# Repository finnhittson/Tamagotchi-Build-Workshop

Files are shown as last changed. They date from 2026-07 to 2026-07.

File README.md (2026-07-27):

# Tamagotchi Build Workshop

This repo documents a Tamagotchi that was created as a lab64 workshop at Stanford University. The idea of the workshop was for students to come into the lab64 makerspace to receive materials and assembly instructions, spend a few hours building, eat a free dinner, and then leave with a fully assembled and functioning Tamagotchi. This project was a collaboration between me, [Sydney Yan](https://www.linkedin.com/in/sydney-yan/), and [Dani Algazi](https://www.linkedin.com/in/dani-algazi-17a7431b2/). I was responsible for creating the PCB, Sydney wrote all the code, and Dani created the enclosure. To see our Tamagotchi in action please visit this [link](https://youtu.be/EQx-8vsQdow).
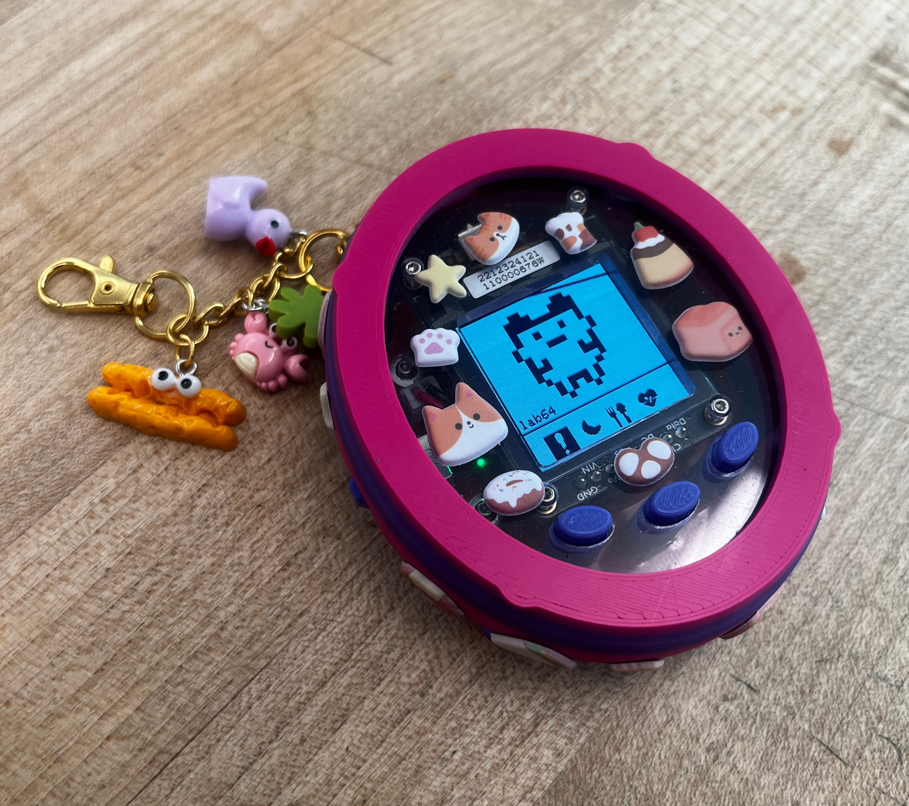
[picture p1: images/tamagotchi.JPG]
tamagotchi


## Electrical

The electronics inside the Tamagotchi were a custom PCB that utilized a [ItsyBitsy](https://www.adafruit.com/product/3675?srsltid=AfmBOooAwEcHuKG2jr8HvIwYrDCV_mU2HbkCFx2qz2rQIsxoqrmatH5F) microcontroller, [128x128 OLED Graphic Display](https://www.adafruit.com/product/5297) by Adafruit, a [2000mAh battery](https://www.adafruit.com/product/2011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), three buttons, and a few other electronics. A full bill of materials is avaliable in the `electrical/` directory. A schematic of the circuit is the following image.

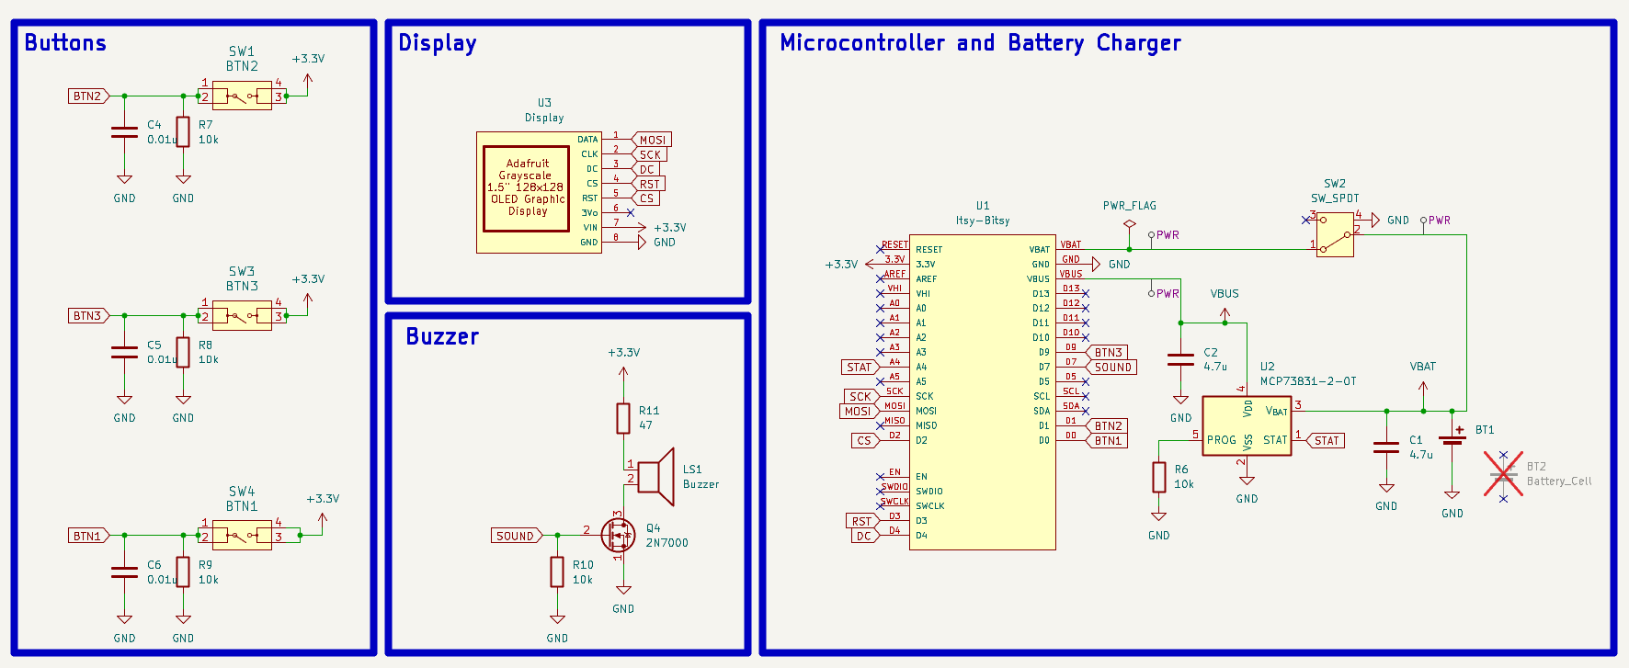
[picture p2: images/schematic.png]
schematic


The buttons are the main control buttons for the Tamagotchi. They are nominally pulled up and go low when pressed. There is also a bypass capacitor to help eliminate switch bounce. The display is controlled by the ItsyBitsy microcontroller through a SPI bus and displays the Tamagotchi and all of its actions. The buzzer is for added sound effects but was never implemented in software due to time constraints. The final block is the ItsyBitsy microcontroller which is connected to a one cell LiPo battery charger circuit. The battery output voltage is fed through a power switch which is then ORed with the VBUS voltage, if present, on the ItsyBitsy breakout board to be regulated to 3.3V and power all other devices. The PCB layout is the following image.

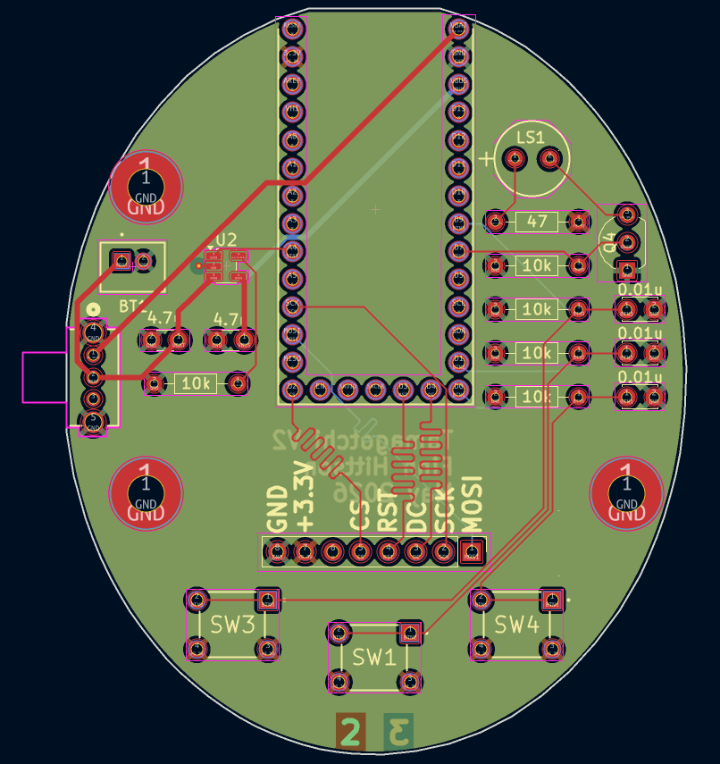
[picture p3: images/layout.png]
layout


The shape is an oval since most real Tamagotchi's are "egg" shaped. The SPI bus lines are length matched not because we expect to use this board at very high frequencies, but rather because it looks cool and I wanted to try it. At the bottom of the PCB are embedded board labels to make sure the stack up was done in the correct order. We opted for three mounting holes due to spacing and because any plane can be constrained by only three points of contact. The following images are renderings of the PCB with and without the display.

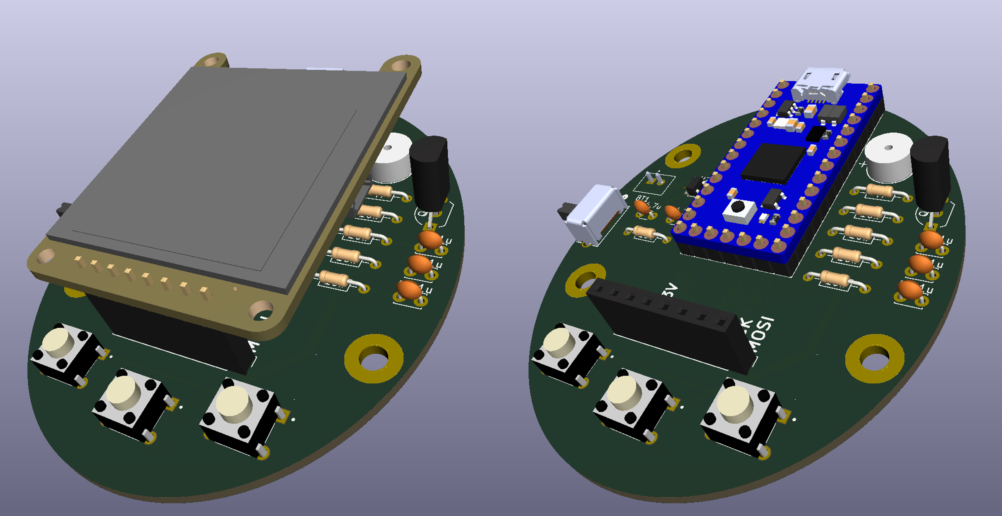
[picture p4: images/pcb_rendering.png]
pcb_rendering


## Software

The software for the Tamagotchi was created and written by [Sydney Yan](https://www.linkedin.com/in/sydney-yan/). Her [repository](https://github.com/sydneyyan/lab64-tamagotchi/tree/main) has installation instructions. The code is structured as an event driven framework. The events were defined as button presses which let the user move their cursor selection between the different actions. The outside most buttons move the cursor either left or right and the middle button is the select button.

cursor

Then the middle button allows the user to select the action, and the Tamagotchi would do the action. The actions are screaming, exercising (running), sleeping, and eating (farting).

actions

The images of the Tamagotchi are then translated as a bitmap to the display. We found many images online of Tamagotchi characters and their actions in bitmap images and translated them manually to an array of ones and zeros to be displayed on the OLED 128x128 display. An example of one of these images we considered was the following. With each button press the display changes the bitmap of the Tamagotchi character or the cursor selection to give the animation effect. 

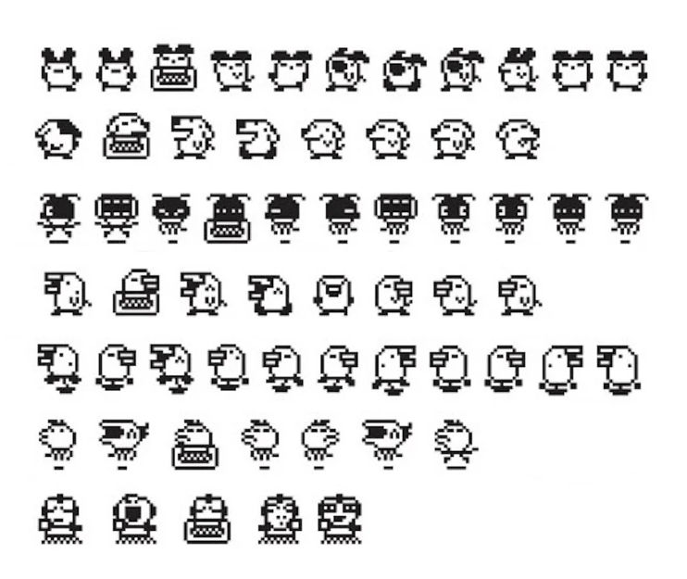
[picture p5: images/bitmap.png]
bitmap


## Mechanical

The enclosure was created and designed by [Dani Algazi](https://www.linkedin.com/in/dani-algazi-17a7431b2/). His Onshpae file for this project is so beautifully organized you have to see [it](https://cad.onshape.com/documents/d4130be6a1970f53ef730a90/w/6fa9feb7c0a58738c3d2d12f/e/90ee6ce4a11ee68d4a759c51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) for yourself. 
The enclosure is made of three main pieces; the top and bottom part of the enclosure, and the front cover. The following exploded view of the assembly shows these parts.

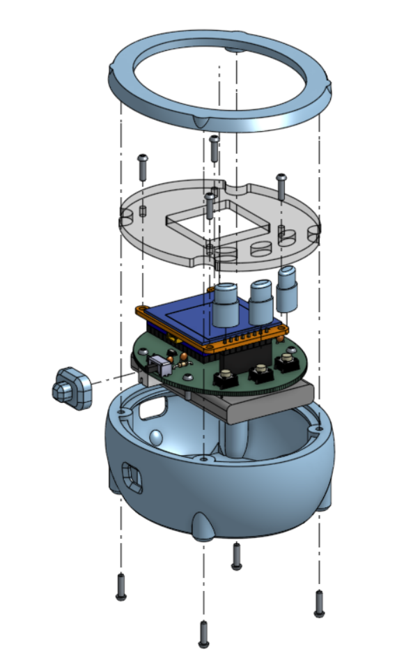
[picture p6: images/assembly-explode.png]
assembly-exploded


The bottom piece holds the battery and the  PCB in place with heat set inserts embedded into the frame. The translucent front cover piece snaps into the top part of the enclosure. This then fits to the bottom part of the enclosure, sealing the electronics inside. The top part of the enclosure has heat set inserts and screws to the bottom part of the enclosure. We also had to add button and switch extenders so that the user could press the buttons and flip the power switch from the outside of the enclosure. Fully assembled the Tamagotchi 3D rendering looks like the following. The files `Assembly Instructions.pdf` describe how to assemble a Tamagotchi with many more photos explaining each step.
comparison

## Special Thanks

Huge thank you to Dani and Sydney for helping me create this. It was a ton of fun to work with you and see our rendition of Tamagotchi come to life. Lets do it again.

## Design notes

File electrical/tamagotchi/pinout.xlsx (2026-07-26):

Net Name | IO | Pin Number | Description | Line states
BTN3 | Input | D5 | Left button | Line HIGH when pressed, LOW when not pressed
BTN2 | Input | D1 | Middle button | Line HIGH when pressed, LOW when not pressed
CS | Output | D3 | Chip select line for display | LOW when selecting the display and HIGH when not selecting
MOSI | Output | MOSI | Data line from ItsyBitsy to display | Data line
SOUND | Output | D7 | PWM line to control buzzer | PWM line
BTN1 | Input | D0 | Right button | Line HIGH when pressed, LOW when not pressed
SCK | Output | SCK | SPI clock line | SPI bus clock line
STAT | Input | A4 | Battery charge status from battery charger IC | LOW is battery charging, HIGH is battery charging complete
RST | Output | D2 | Reset pin for display | Reset line, active LOW
DC | Output | D4 | Data or command selector pin. Tells display controller whether incomming packet is data or a command | HIGH is for data, LOW is for command

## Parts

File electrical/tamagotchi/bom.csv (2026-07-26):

Reference | Qty | Value | Supplier | Supplier PN
BT1 | 50 | Battery_Conn | DigiKey | 455-1704-ND
BT2 | 50 | Battery_Cell | DigiKey | 1528-1857-ND
C1,C2 | 100 | 4.7u | DigiKey | 399-14393-2-ND
C4,C5,C6 | 150 | 0.01u | DigiKey | BC1084TR-ND
LS1 | 50 | Speaker | DigiKey | 433-1192-ND
R6,R7,R8,R9,R10 | 250 | 10k | DigiKey | CF14JT10K0TR-ND
SW1 | 150 | BTN2 | DigiKey | EG1829-ND
SW2 | 50 | SW_SPDT | DigiKey | CKN9559-ND
U1 | 50 | Itsy-Bitsy | DigiKey | 1528-2619-ND
U2 | 50 | MCP73831-2-OT | DigiKey | MCP73831T-2ACI/OTTR-ND
U3 | 50 | Display | Adafruit | 4741

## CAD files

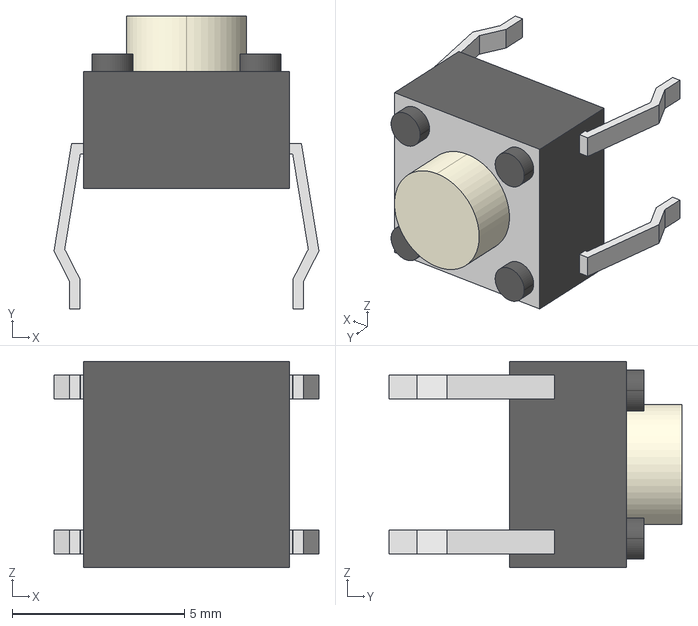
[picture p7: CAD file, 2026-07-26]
electrical/tamagotchi/3d_models/b3f-1020.stp
7.70 x 8.50 x 6.00 mm

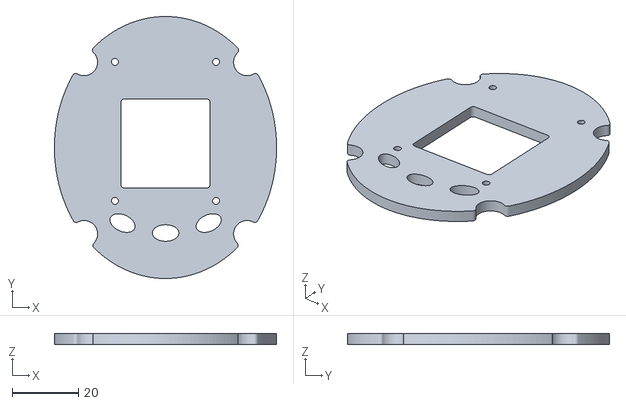
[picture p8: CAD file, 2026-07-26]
mechanical/Front Cover.stl
67.0 x 79.0 x 3.17

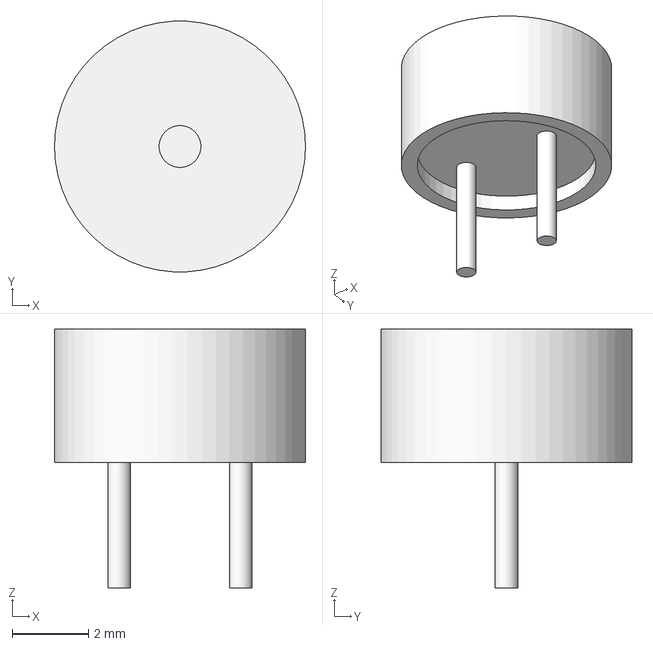
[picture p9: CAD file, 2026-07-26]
electrical/tamagotchi/3d_models/buzzer.stp
6.60 x 6.59 x 6.80 mm

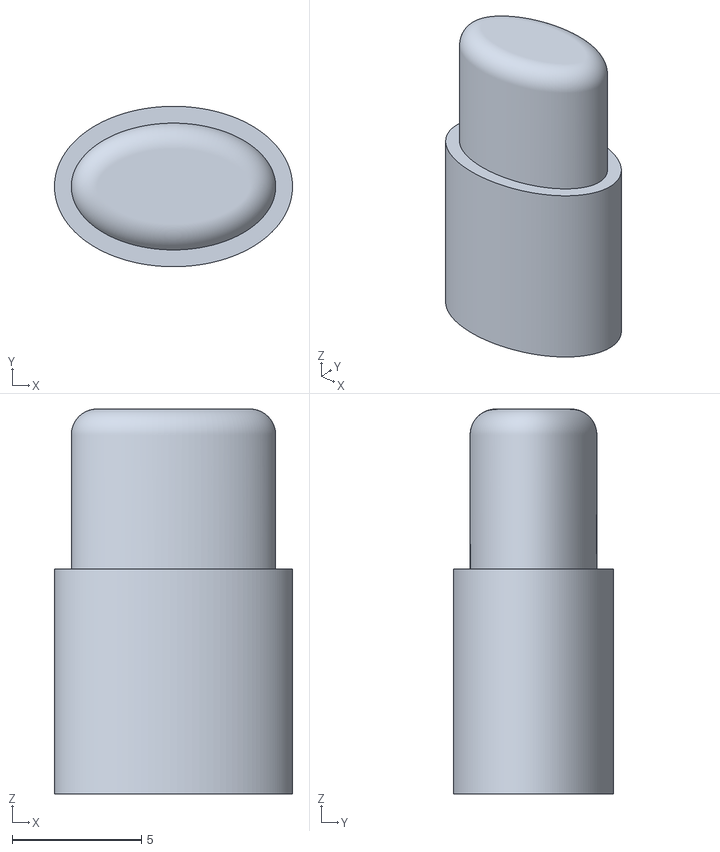
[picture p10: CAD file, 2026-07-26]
mechanical/Button Cap.stl
9.20 x 6.20 x 14.9

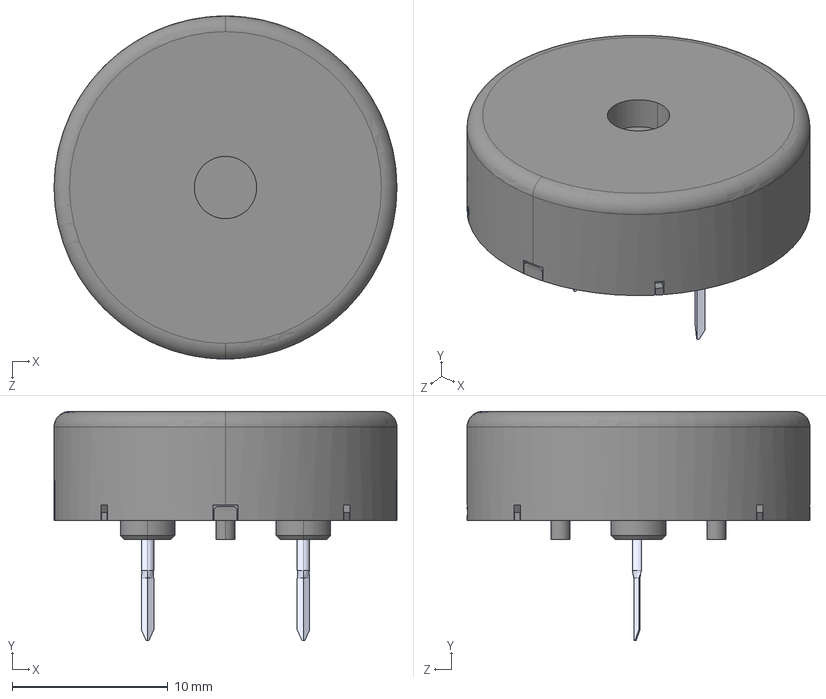
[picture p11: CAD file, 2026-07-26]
electrical/tamagotchi/3d_models/Speaker.STEP
22.0 x 14.7 x 22.0 mm

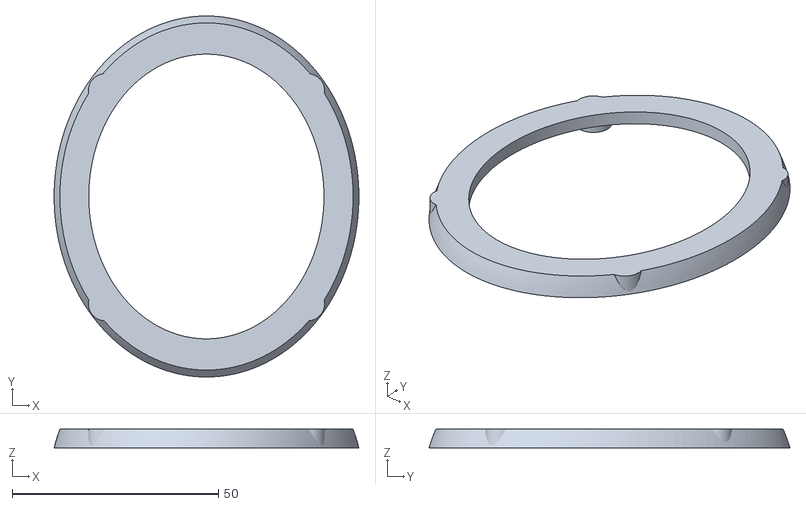
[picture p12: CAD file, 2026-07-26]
mechanical/Top Enclosure.stl
73.9 x 87.5 x 4.59

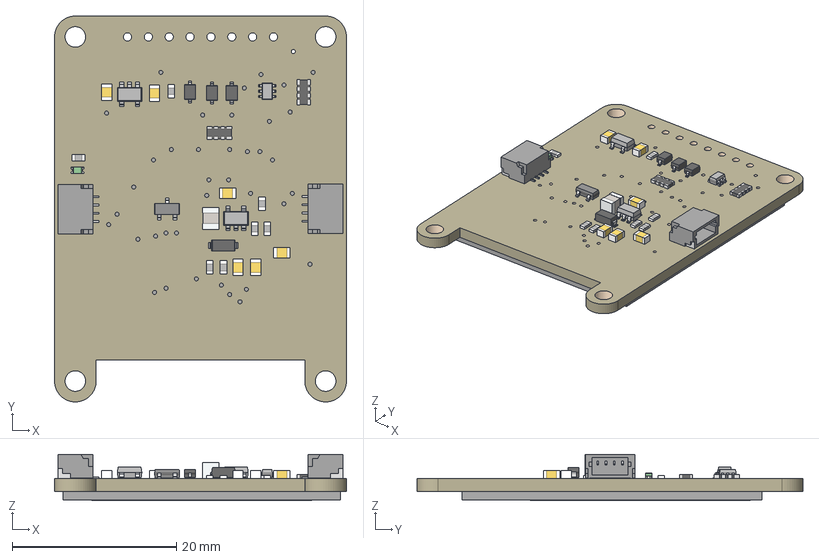
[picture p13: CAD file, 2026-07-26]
electrical/tamagotchi/3d_models/1.5-inch OLED.step
35.6 x 47.0 x 5.63 mm
Board
10uF x 6
AP2112K-3.3
0.1uF x 7
10K x 2
BSS138
STEMMA_I2C_QT x 2
GREEN
APX803
1N4148 x 3
OLED_1.5_128X128_MONO
FAN5331SX
10uH
MBR120

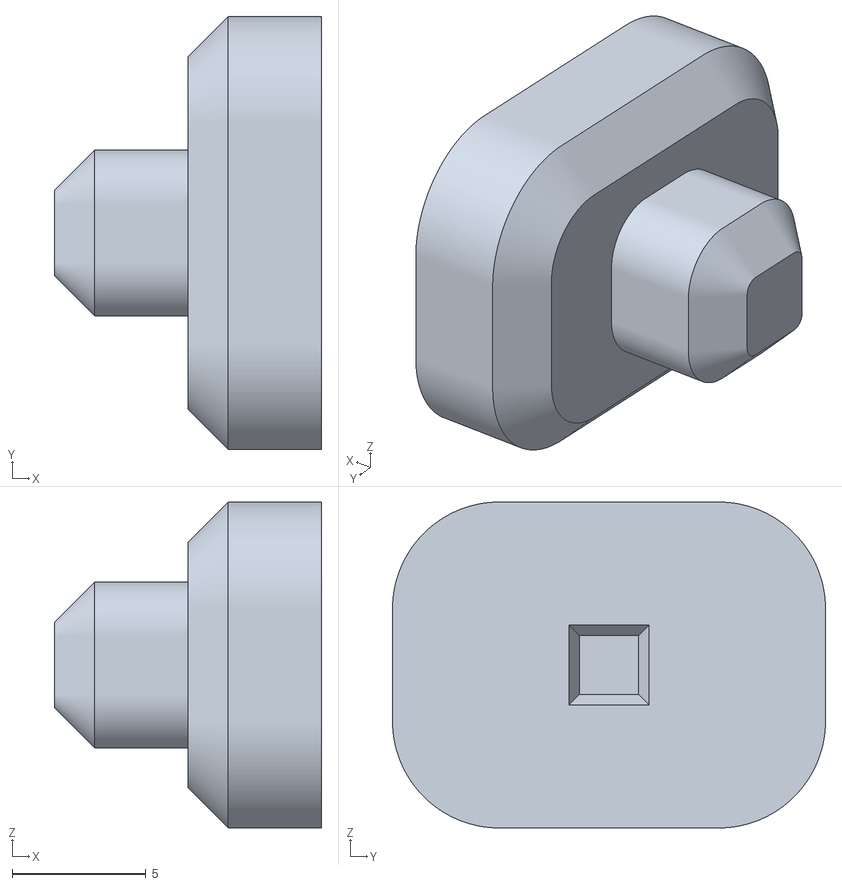
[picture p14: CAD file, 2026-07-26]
mechanical/Switch Cover.stl
10.00 x 16.2 x 12.2

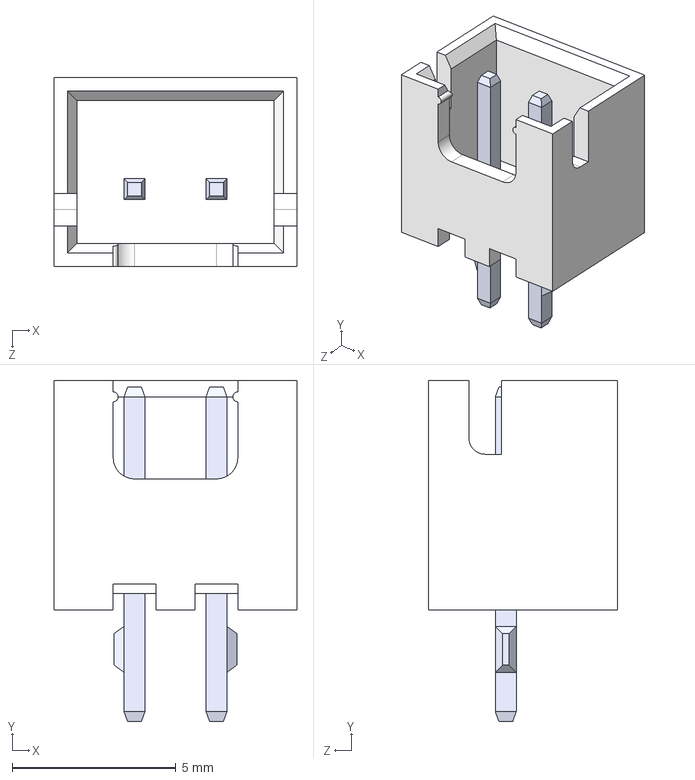
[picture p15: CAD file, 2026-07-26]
electrical/tamagotchi/3d_models/B2B-XH-A.step
7.40 x 10.4 x 5.75 mm

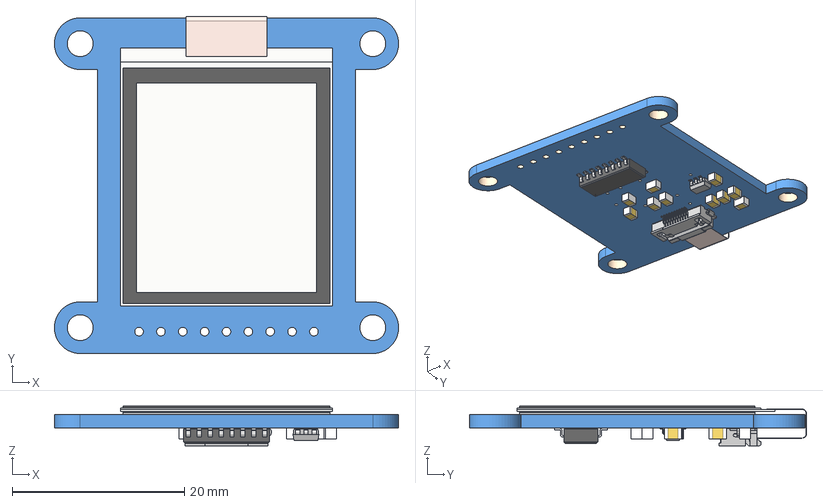
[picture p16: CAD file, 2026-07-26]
electrical/tamagotchi/3d_models/display.step
40.0 x 39.2 x 4.60 mm
Board
LS013B4DN04
10µF x 10
74HC4050D
MCP1824T-3302E/OT
TFT Glass
Top Glass
Top Polarizer
Bottom Polarizer
Mounting tape

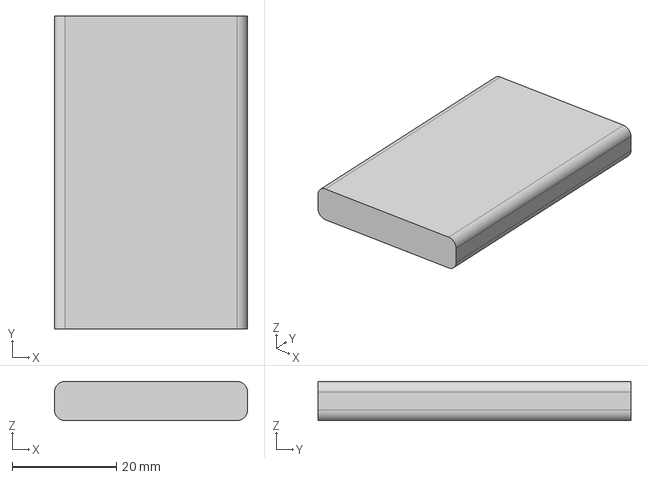
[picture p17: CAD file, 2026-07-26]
electrical/tamagotchi/3d_models/2000mAh Battery.step
37.0 x 60.0 x 7.50 mm

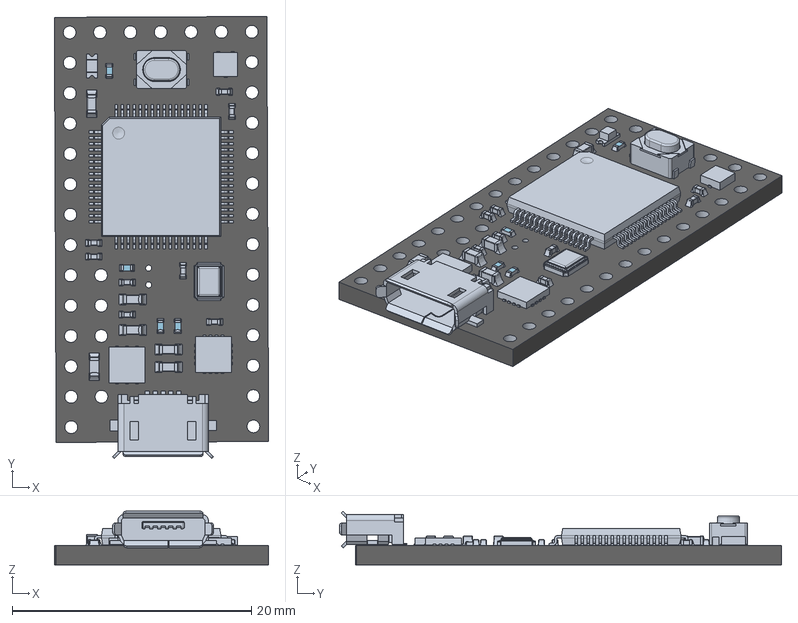
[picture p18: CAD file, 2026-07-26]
electrical/tamagotchi/3d_models/Teensy_3.2.stp
17.9 x 37.0 x 4.49 mm
board
micro_usb_plastic (1)
micro_usb_shell (1)
lead
package (1)
lead (3) x 64
package
lead (1)
cap0402 v2 x 6
lead (2)
diode_0402 v1 x 4
cap0603_03 v3 x 5
cap0402 v2 (1) x 2
smt_led_0805 v2
resistor_0603 v3

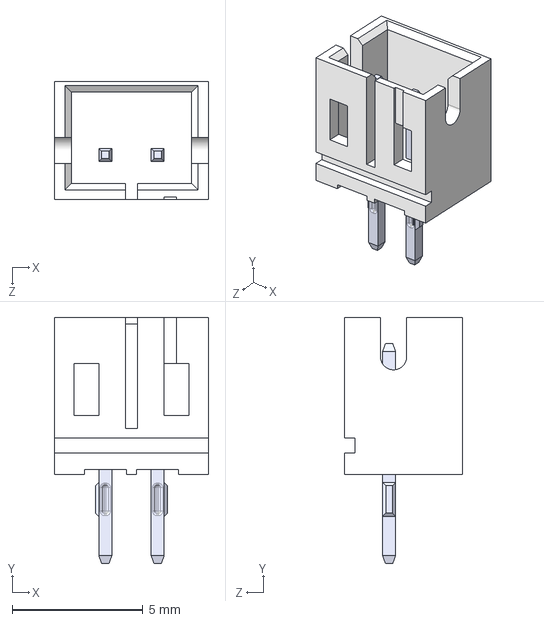
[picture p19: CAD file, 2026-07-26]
electrical/tamagotchi/3d_models/2mm-JST-PH.STEP
5.90 x 9.40 x 4.50 mm

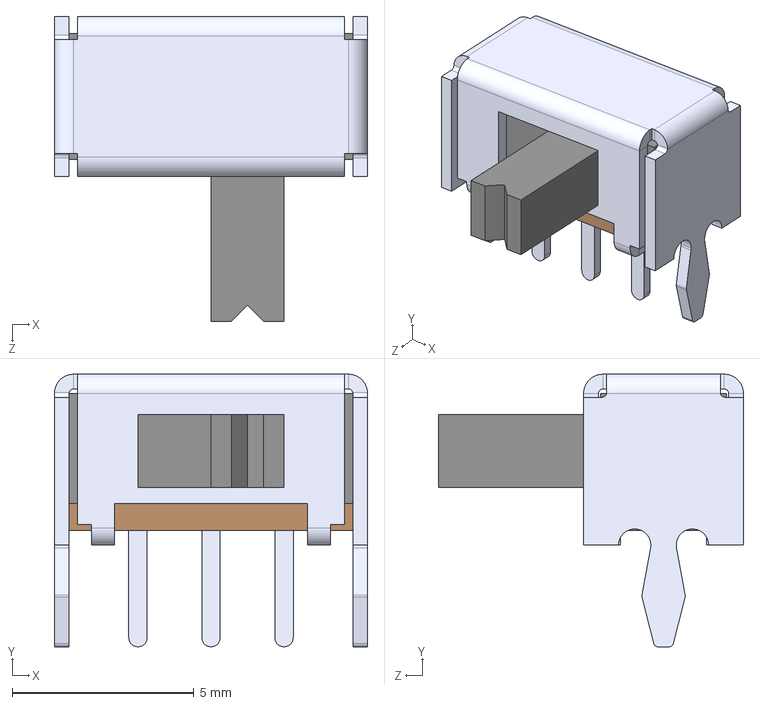
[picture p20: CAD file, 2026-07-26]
electrical/tamagotchi/3d_models/OS102011MA1QN1.STEP
8.61 x 7.49 x 8.38 mm

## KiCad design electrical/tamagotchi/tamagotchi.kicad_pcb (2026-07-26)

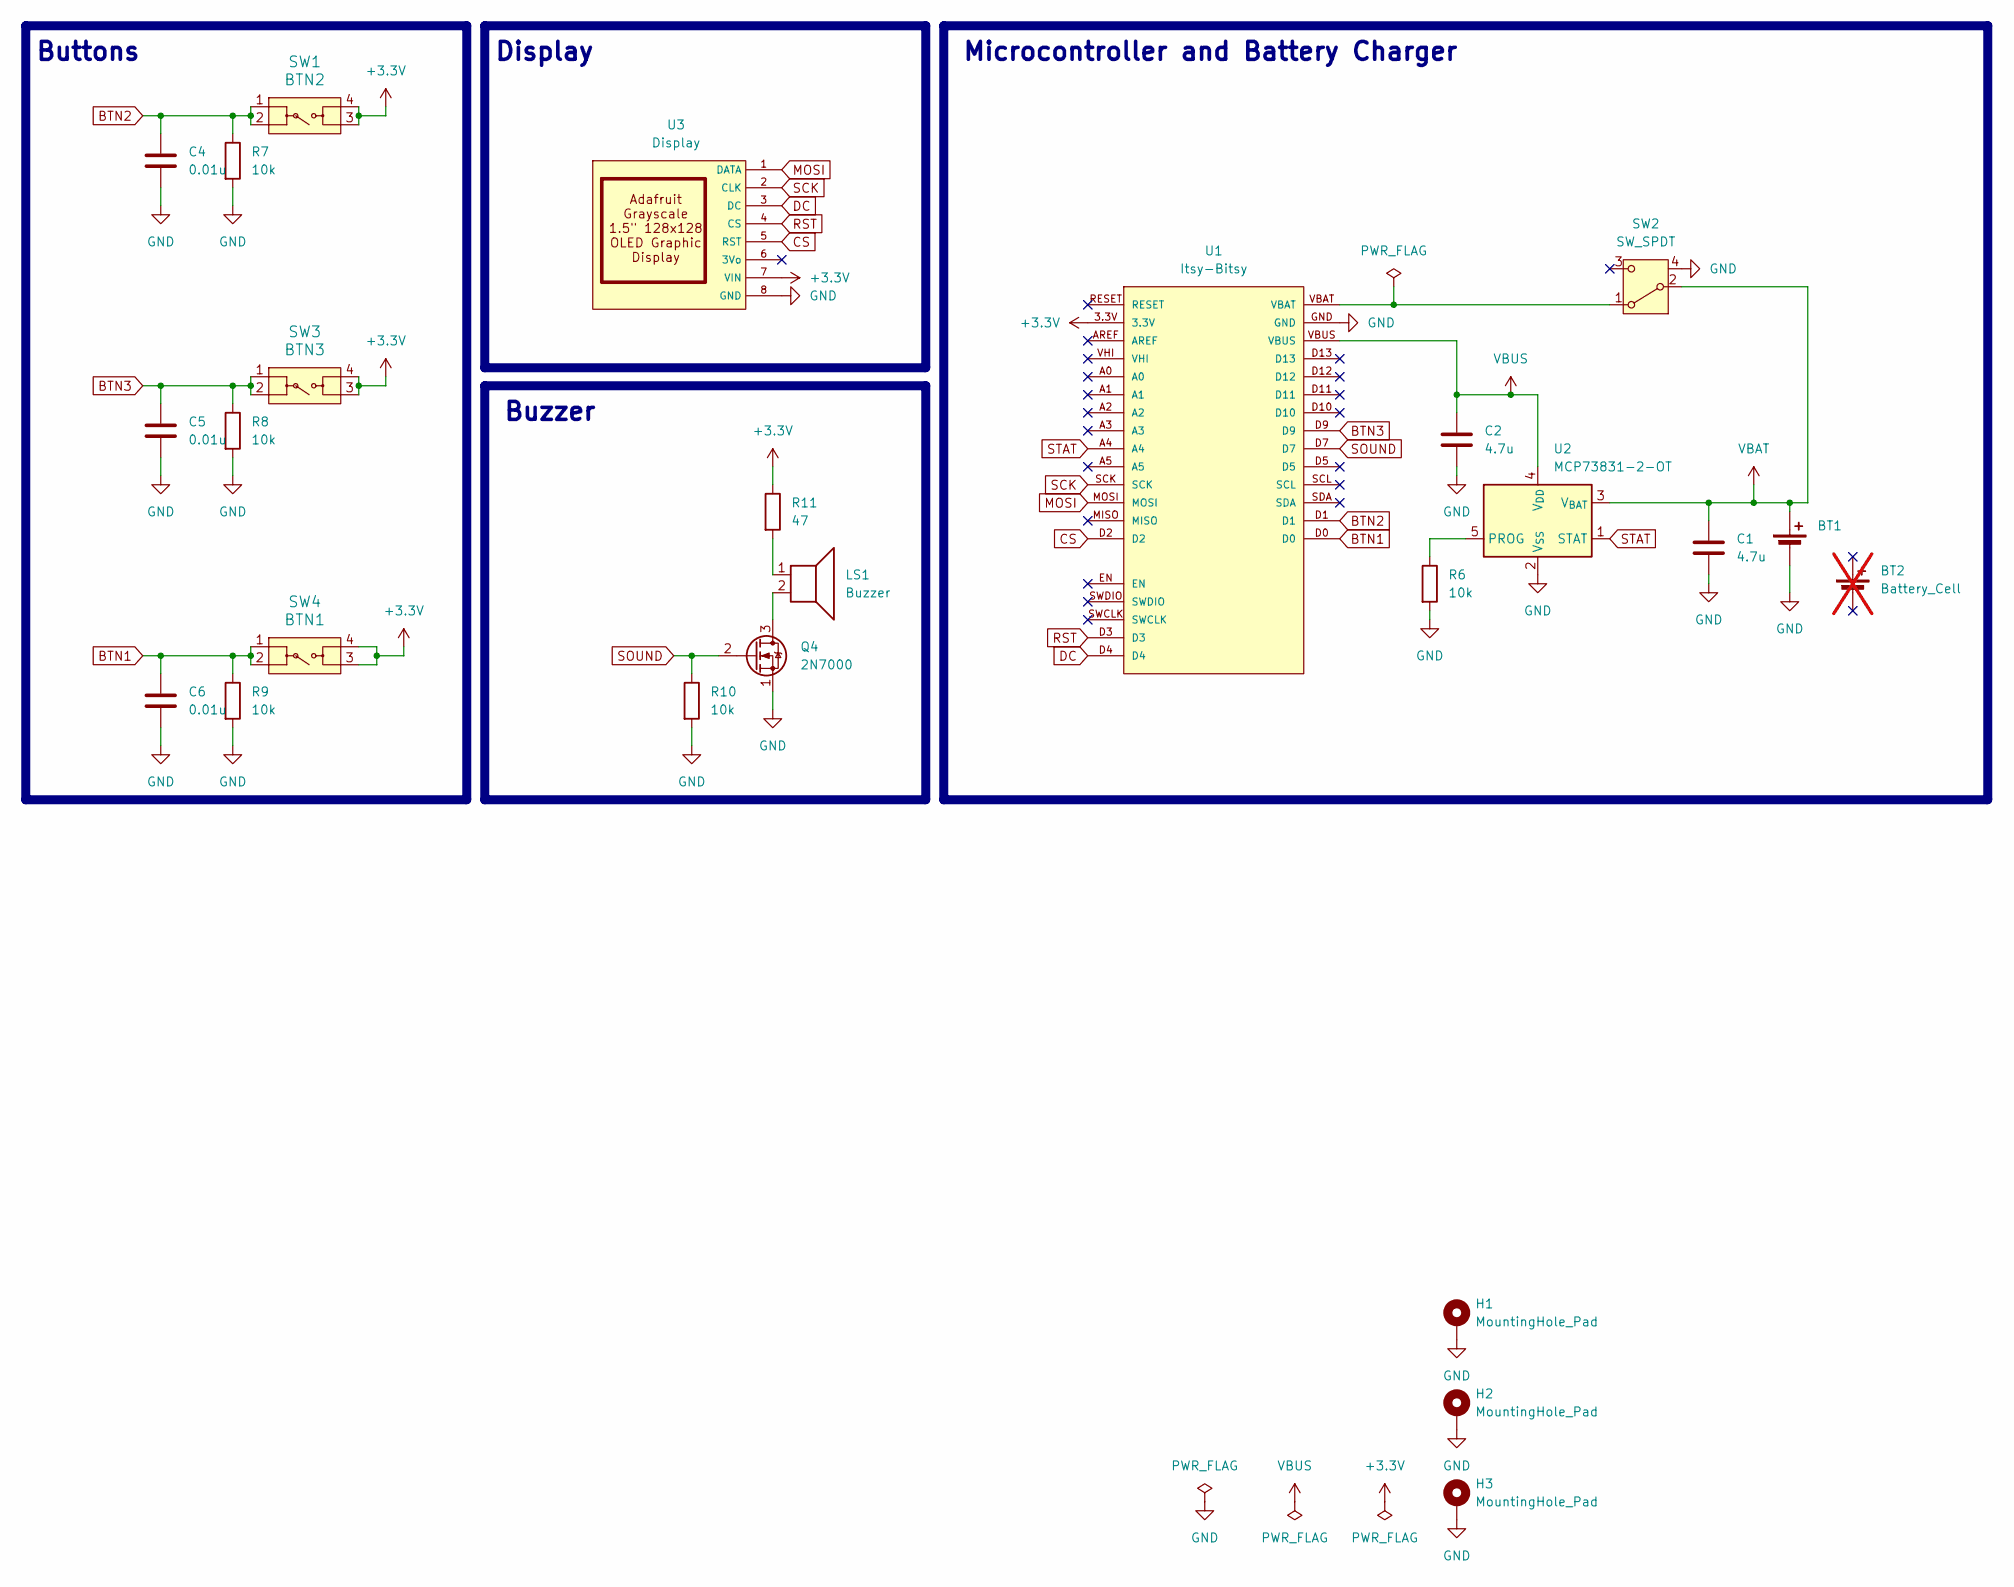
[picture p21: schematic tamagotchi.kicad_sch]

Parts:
BT1: Battery_Conn; 2mm-JST-PH
BT2: Battery_Cell; not fitted
C1, C2: 4.7u; C_Disc_D3.0mm_W1.6mm_P2.50mm
C4, C5, C6: 0.01u; C_Disc_D3.0mm_W2.0mm_P2.50mm
H1, H2, H3: MountingHole_Pad; MountingHole_3.2mm_M3_Pad_TopBottom
LS1: Buzzer; TO_0601A_SOB
Q4: 2N7000; TO-92L_Inline_Wide
R6, R7, R8, R9, R10: 10k; R_Axial_DIN0204_L3.6mm_D1.6mm_P7.62mm_Horizontal
R11: 47; R_Axial_DIN0204_L3.6mm_D1.6mm_P7.62mm_Horizontal
SW1: BTN2; SW_TL1105AF160Q
SW2: SW_SPDT; OS102011MA1QN1_CNK
SW3: BTN3; SW_TL1105AF160Q
SW4: BTN1; SW_TL1105AF160Q
U1: Itsy-Bitsy; MODULE_DEV-15583
U2: MCP73831-2-OT; SOT-23-5
U3: Display; PinHeader_1x08_P2.54mm_Vertical

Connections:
+3.3V: R11.1, SW1.3, SW1.4, SW3.3, SW3.4, SW4.3, SW4.4, U1.3.3V, U3.7 (VIN)
BTN1: C6.1, R9.1, SW4.1, SW4.2, U1.D0
BTN2: C4.1, R7.1, SW1.1, SW1.2, U1.D1
BTN3: C5.1, R8.1, SW3.1, SW3.2, U1.D9
CS: U1.D2, U3.5 (RST)
DC: U1.D4, U3.3 (DC)
GND: BT1.2 (-), C1.2, C2.2, C4.2, C5.2, C6.2, H1.1 (1_1), H2.1 (1_1), H3.1 (1_1), Q4.1 (S), R6.2, R7.2, R8.2, R9.2, R10.2, SW2.4, SW2.5, U1.GND, U2.2 (V_{SS}), U3.8 (GND)
MOSI: U1.MOSI, U3.1 (DATA)
unnamed: LS1.1, R11.2
unnamed: LS1.2, Q4.3 (D)
unnamed: SW2.1 (A), U1.VBAT
unnamed: R6.1, U2.5 (PROG)
RST: U1.D3, U3.4 (CS)
SCK: U1.SCK, U3.2 (CLK)
SOUND: Q4.2 (G), R10.1, U1.D7
STAT: U1.A4, U2.1 (STAT)
VBAT: BT1.1 (+), C1.1, SW2.2 (B), U2.3 (V_{BAT})
VBUS: C2.1, U1.VBUS, U2.4 (V_{DD})

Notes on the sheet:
Display
Buttons
Buzzer
Microcontroller and Battery Charger

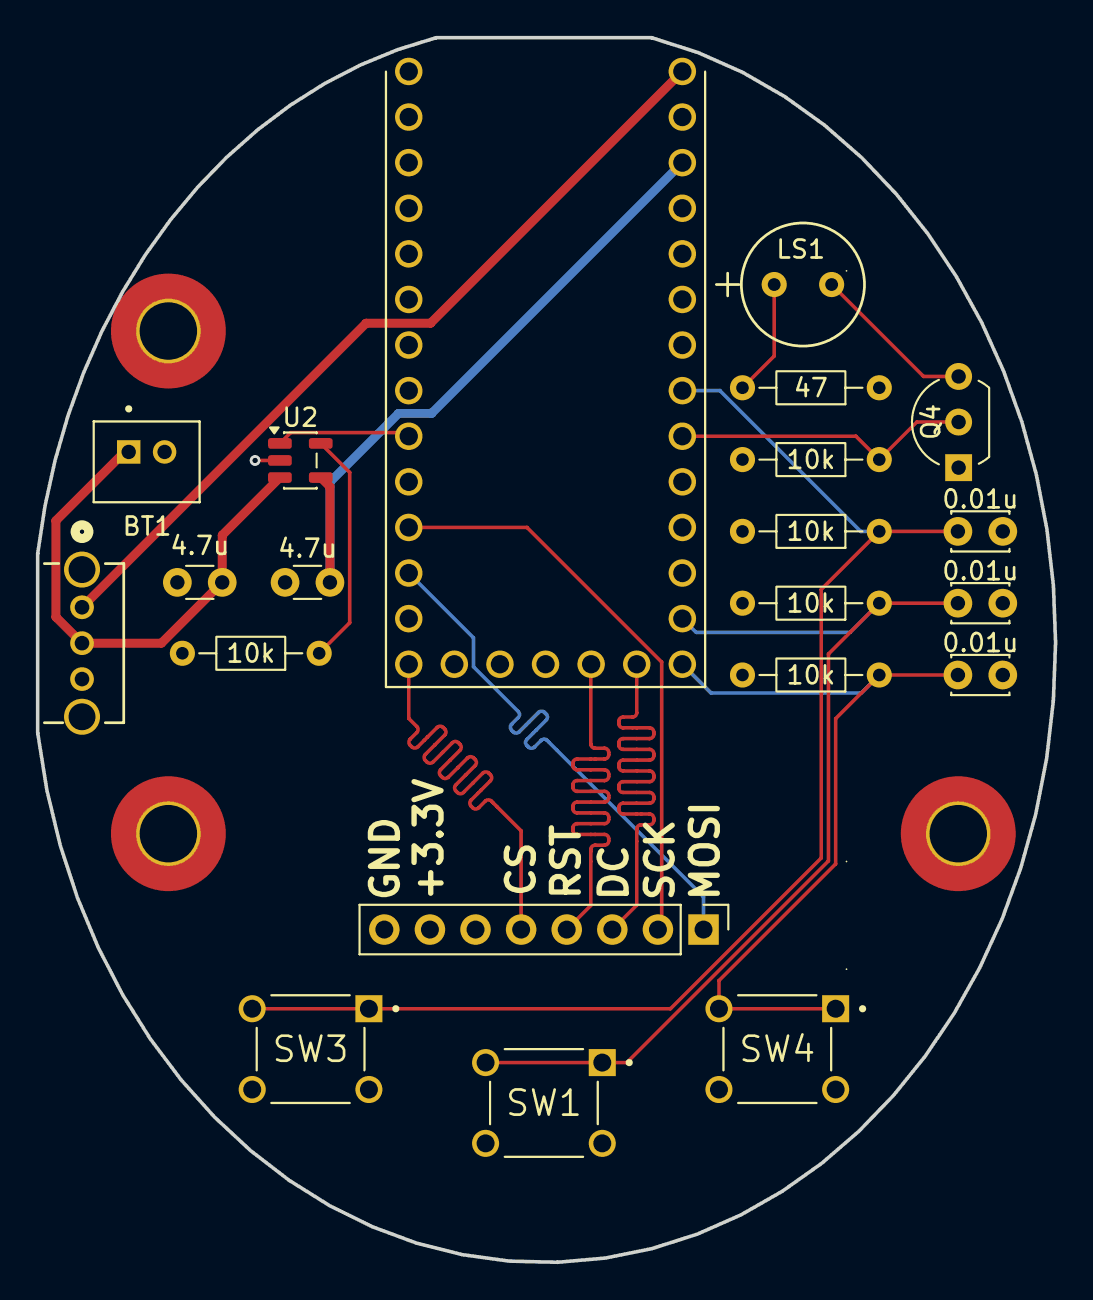
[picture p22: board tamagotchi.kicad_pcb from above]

Board: 4 copper layers, 56.7 x 68.2 mm, 24 parts (0 on the bottom side), 18 nets.

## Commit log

2026-07-26 Add bulk of files
    [1.5-inch OLED.step, 2000mAh Battery.step, 2mm-JST-PH.STEP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]
2026-07-26 Update schematic
    [tamagotchi.kicad_pcb, tamagotchi.kicad_sch]
2026-07-26 Combine pcb rendering images
